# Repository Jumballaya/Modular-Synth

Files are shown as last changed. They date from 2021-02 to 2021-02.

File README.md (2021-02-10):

# Modular Synth, Eurorack compatible

## Contents

1. Case
2. Power Supply
3. Modules
    - VCO

## Case

The case design is currently being worked on.

## Power Supply

The power supply is compatible with the Eurorack 16 pin standard delivering +12V, -12V, +5V and CV/Gate information. The power supply uses a 12V AC wall wart and has power outputs.

## Modules

### VCO

The VCO is still being designed. I am currently planning for 1V/octave with a wave -10V to 10V, either Triangle, Saw or a Square wave with a pulse-width modulation potentiometer as well as a course and fine volume controls.

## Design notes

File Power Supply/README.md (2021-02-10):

# Power Supply

This power supply uses an L7812, L7912 and LM7805 as voltage regulators to create +12V, -12V and +5V power rails. Each voltage regulator has a 1uF capacitor tied to ground on both the input and output as well as 3 4700uF capacitors as buffer from the power input.

There are 6 IDC, 16 pin, headers for powering modules. The board has each row marked and a number '1' near the red stripe row.

## 3D Render
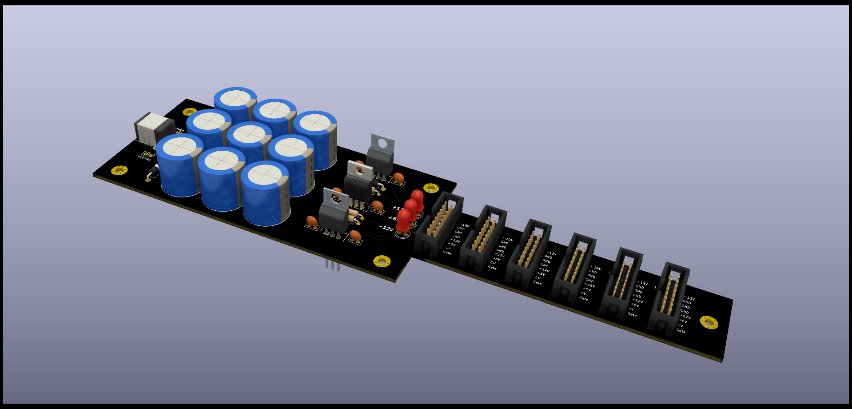
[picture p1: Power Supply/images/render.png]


## Schematic
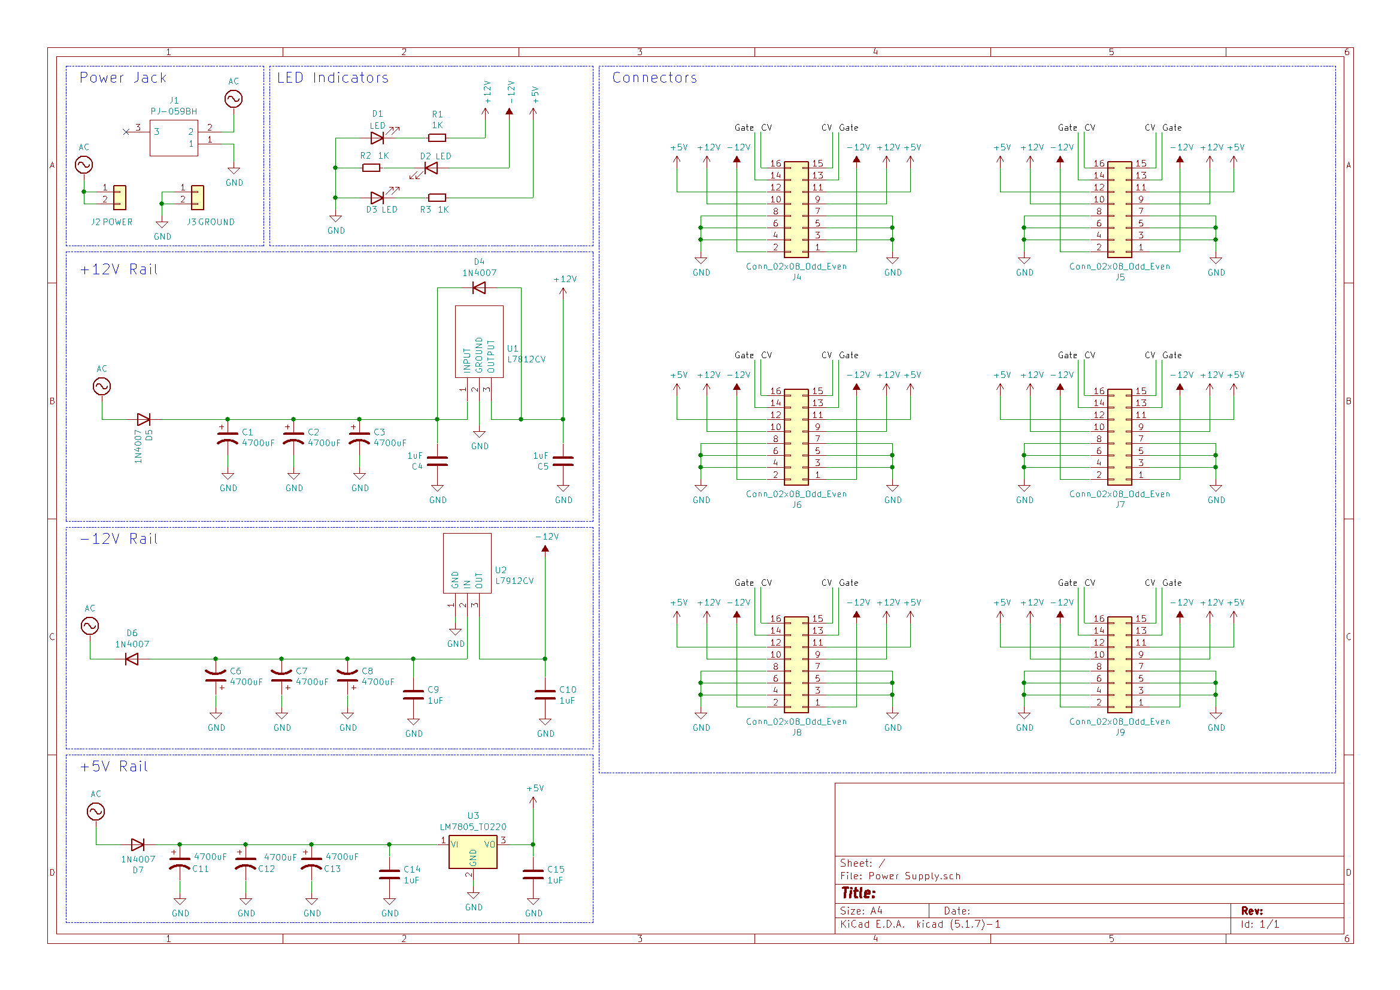
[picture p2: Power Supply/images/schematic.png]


## Layout

#### Front


#### Back


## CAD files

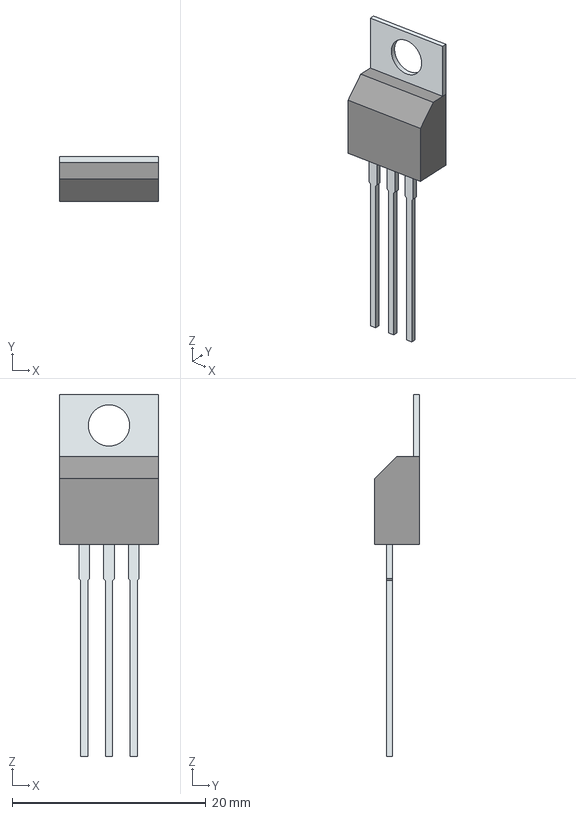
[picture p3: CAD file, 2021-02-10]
Power Supply/external_libs/l7812cv/3D/L7812CV.stp
10.2 x 4.60 x 37.4 mm
Tab
PinsArray

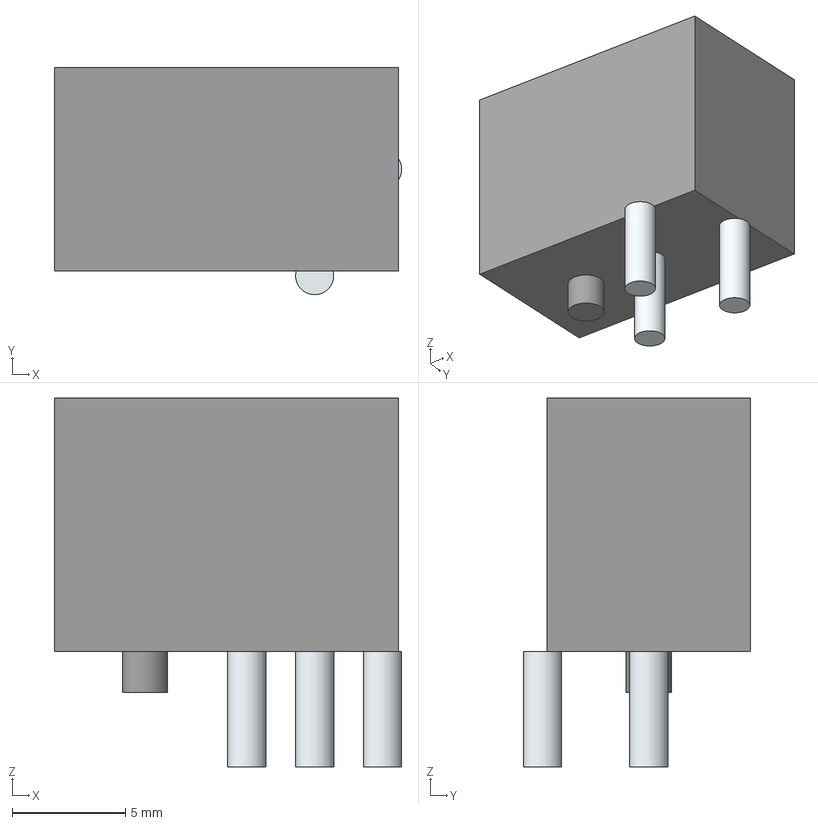
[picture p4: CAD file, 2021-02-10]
Power Supply/external_libs/PJ-059BH/3D/PJ-059BH.stp
15.3 x 10.0 x 16.3 mm
Lugs x 4
Leads x 4

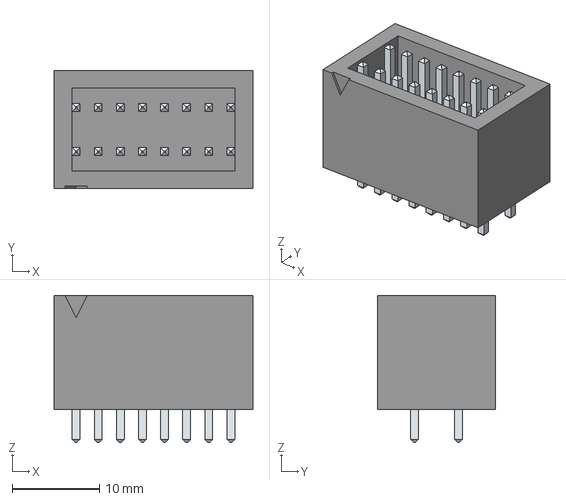
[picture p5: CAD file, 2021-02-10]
Power Supply/external_libs/61201621621/3D/61201621621.stp
22.9 x 13.6 x 16.9 mm
LeadsArray

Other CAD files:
Power Supply/external_libs/l7912cv/3D/L7912CV.stp
Power Supply/external_libs/61201621621/3D/61201621621.stl
Power Supply/external_libs/PJ-059BH/3D/PJ-059BH.stl
Power Supply/external_libs/l7812cv/3D/L7812CV.stl
Power Supply/external_libs/l7912cv/3D/L7912CV.stl

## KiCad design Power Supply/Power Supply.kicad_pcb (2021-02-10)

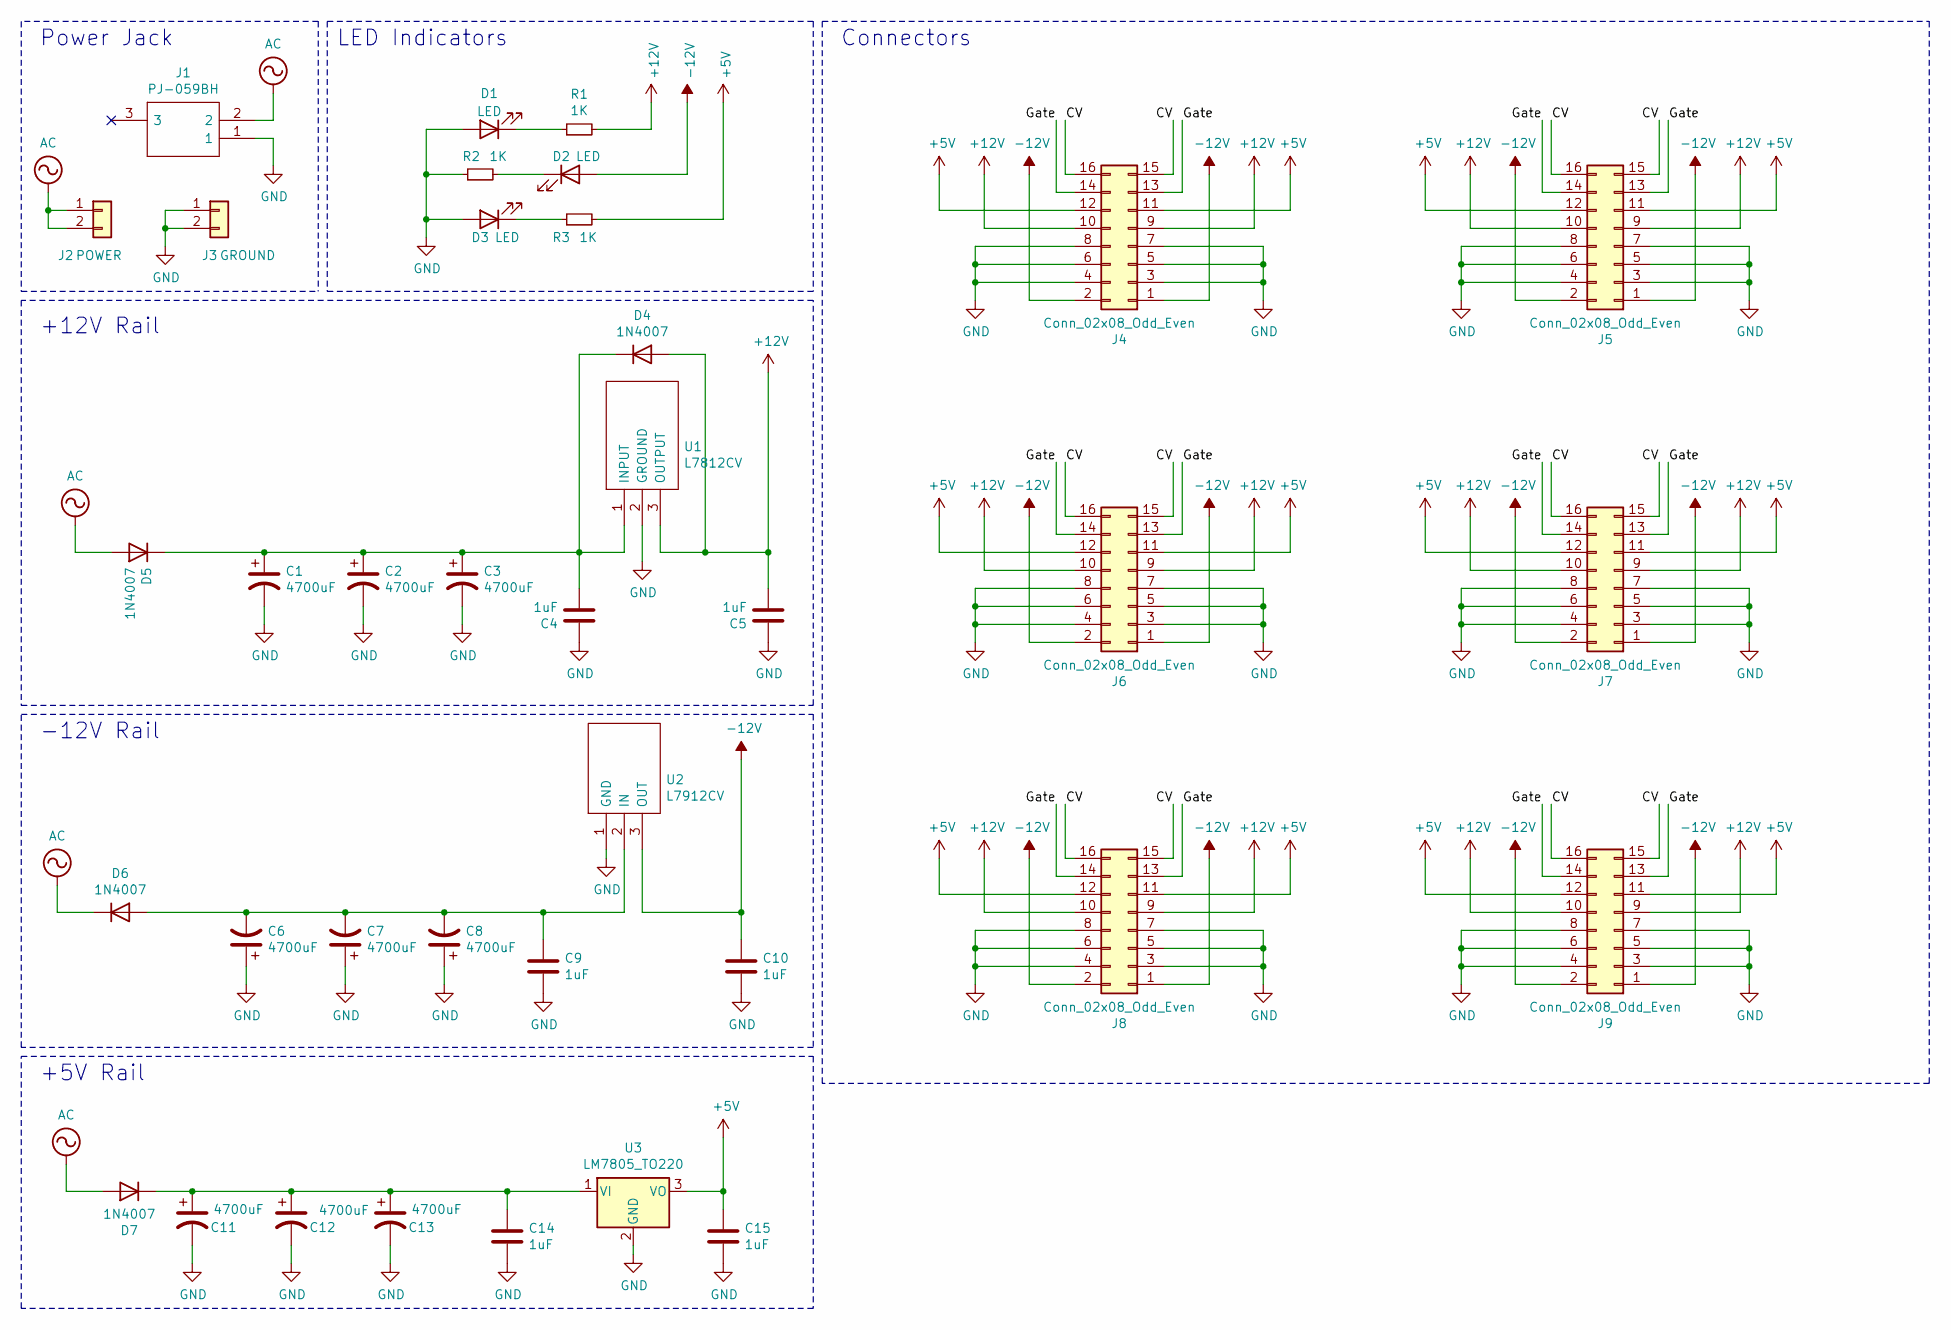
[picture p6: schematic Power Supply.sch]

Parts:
C1, C2, C3, C6, C7, C8, C11, C12, C13: 4700uF; CP_Radial_D18.0mm_P7.50mm
C4, C5, C9, C10, C14, C15: 1uF; C_Disc_D5.0mm_W2.5mm_P2.50mm
D1, D2, D3: LED; LED_D5.0mm
D4, D5, D6, D7: 1N4007; D_DO-41_SOD81_P10.16mm_Horizontal
J1: PJ-059BH; PJ059BH; Mouser Part Number 490-PJ-059BH
J2: POWER; PinHeader_1x02_P2.54mm_Vertical
J3: GROUND; PinHeader_1x02_P2.54mm_Vertical
J4, J5, J6, J7, J8, J9: Conn_02x08_Odd_Even; PinHeader_2x08_P2.54mm_Vertical
R1, R2, R3: 1K; R_Axial_DIN0207_L6.3mm_D2.5mm_P10.16mm_Horizontal
U1: L7812CV; TO255P460X1020X2008-3P; Mouser Part Number 511-L7812CV
U2: L7912CV; TO255P460X1020X2008-3P; Mouser Part Number 511-L7912CV
U3: LM7805_TO220; TO-220-3_Vertical

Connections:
+5V: C15.1, J4.11, J4.12, J5.11, J5.12, J6.11, J6.12, J7.11, J7.12, J8.11, J8.12, J9.11, J9.12, R3.2, U3.3 (VO)
+12V: C5.2, D4.2 (A), J4.9, J4.10, J5.9, J5.10, J6.9, J6.10, J7.9, J7.10, J8.9, J8.10, J9.9, J9.10, R1.2, U1.3 (OUTPUT)
-12V: C10.1, D2.2 (A), J4.1, J4.2, J5.1, J5.2, J6.1, J6.2, J7.1, J7.2, J8.1, J8.2, J9.1, J9.2, U2.3 (OUT)
/CV: J4.15, J4.16, J5.15, J5.16, J6.15, J6.16, J7.15, J7.16, J8.15, J8.16, J9.15, J9.16
/Gate: J4.13, J4.14, J5.13, J5.14, J6.13, J6.14, J7.13, J7.14, J8.13, J8.14, J9.13, J9.14
AC: D5.2 (A), D6.1 (K), D7.2 (A), J1.2, J2.1, J2.2
GND: C1.2, C2.2, C3.2, C4.1, C5.1, C6.1, C7.1, C8.1, C9.2, C10.2, C11.2, C12.2, C13.2, C14.2, C15.2, D1.2 (A), D3.2 (A), J1.1, J3.1, J3.2, J4.3, J4.4, J4.5, J4.6, J4.7, J4.8, J5.3, J5.4, J5.5, J5.6, J5.7, J5.8, J6.3, J6.4, J6.5, J6.6, J6.7, J6.8, J7.3, J7.4, J7.5, J7.6, J7.7, J7.8, J8.3, J8.4, J8.5, J8.6, J8.7, J8.8, J9.3, J9.4, J9.5, J9.6, J9.7, J9.8, R2.1, U1.2 (GROUND), U2.1 (GND), U3.2 (GND)
unnamed: C1.1, C2.1, C3.1, C4.2, D4.1 (K), D5.1 (K), U1.1 (INPUT)
unnamed: C6.2, C7.2, C8.2, C9.1, D6.2 (A), U2.2 (IN)
unnamed: C11.1, C12.1, C13.1, C14.1, D7.1 (K), U3.1 (VI)
unnamed: D1.1 (K), R1.1
unnamed: D2.1 (K), R2.2
unnamed: D3.1 (K), R3.1

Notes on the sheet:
-12V Rail
+12V Rail
Power Jack
LED Indicators
+5V Rail
Connectors

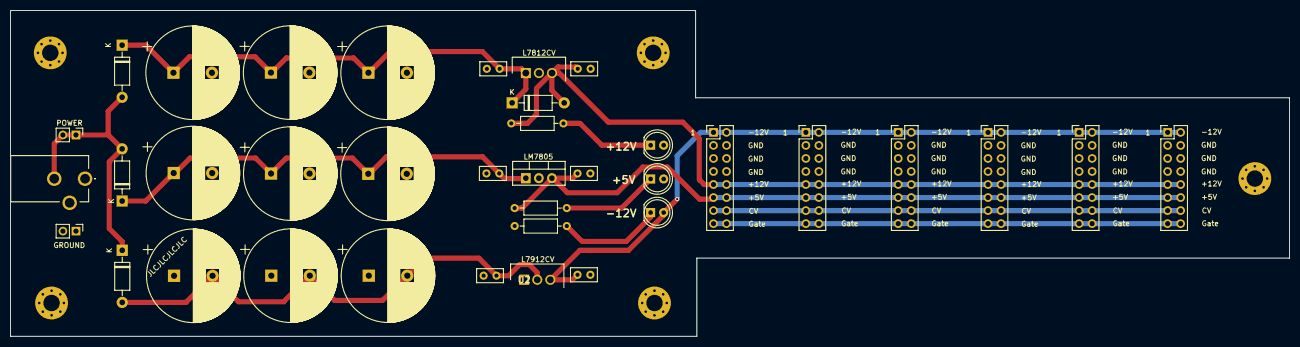
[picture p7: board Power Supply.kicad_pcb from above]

Board: 2 copper layers, 249.2 x 63.5 mm, 37 parts (0 on the bottom side), 13 nets.

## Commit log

2021-02-10 init + add power supply files
    [61201621621.stl, 61201621621.stp, L7812CV.stl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]
2021-02-10 add images + readme to power supply
